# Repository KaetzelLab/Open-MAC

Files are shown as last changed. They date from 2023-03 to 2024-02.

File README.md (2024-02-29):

# Open-MAC
Design files for an open-source motorized all-in-one commutator (Open-MAC).

BOM is updated, and we kindly request the users to refer BOM from GitHub to build the new version of the commutator

#### For Opto-Ephys commutator please visit below link

https://github.com/KaetzelLab/Open-MAC-opto-ephys-commutator.git

## Multi-function overview

1-s2 0-S2468067223000366-gr3

## Overview of Commutator Design

Commutator overviewpng

## Commutator assembly 

https://github.com/KaetzelLab/Open-MAC/assets/71041273/7a731dc8-49ea-48de-bc95-c26bbd119e4d

## Ephys recording during LMA

https://github.com/KaetzelLab/Open-MAC/assets/71041273/e578357a-732e-4ff6-8649-cc418df18f86

# Citation
If you find this repository and documents useful cite us as 

Sampath K.T. Kapanaiah, Dennis Kätzel, (2023). Open-MAC: A low-cost open-source motorized commutator for electro- and opto-physiological recordings in freely moving rodents, HardwareX, Volume 14,2023,e00429, ISSN 2468-0672,https://doi.org/10.1016/j.ohx.2023.e00429.

Kapanaiah, Sampath K.T., & Kätzel, Dennis. (2023). Open-MAC: A low-cost open-source motorized commutator for electro- and opto-physiological recordings in freely moving rodents. https://doi.org/10.5281/zenodo.7640543

# If you are downloading files from zenodo

Please note that relative to v1.1 (currently only available on Zenodo, https://zenodo.org/record/7640543 ) this current version v1.2 contains two improvements:

 (i) The Top case B has been extended in length so that it can now be used for 4 of the 5 Open-MAC versions (12-channel SPI E-Phys, 24-channel SPI E-Phys, 1-channel RF miniscope, combined 12-channel SPI E-Phys/1-channel RF miniscope). As in previous versions, the combined E-Phys/Optogenetics version will require some minor modifications that we hope to release soon.

(ii) The bottom PCB design file, that suffered from one weak GND trace in v1.1 (but not in v1.0) has been updated, so that it is fully functional again.

Hence v1.1 is obsolete and v1.2, released here, should be used.

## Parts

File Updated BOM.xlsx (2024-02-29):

Designator | Component | Number | Cost per unit (EUR) | Total cost (EUR) | Manufacturer Number | Source of material | Material type
Top PCB | Top PCB | 1 | 1.00 | 1.00 | na | JLC PCB or PCB way | printed circuit board
Bottom PCB | Bottom PCB | 1 | 1.00 | 1.00 | na | JLC PCB or PCB way | printed circuit board
Bottom PCB | Hall Sensor | 2 | 0.30 | 0.60 | na | https://www.amazon.de/gp/product/B07ZDJSZSG/ref=ppx_yo_dt_b_asin_title_o04_s00?ie=UTF8&psc=1 | IC
Top PCB, Bottom PCB | slide switch | 2 | 0.42 | 0.84 | 1825232-1 | https://www.mouser.de/ProductDetail/TE-Connectivity-PB/1825232-1?qs=kTKVN3NWb5FosGxaNC1%252BtA%3D%3D | Plastic, Metal
Top PCB | Linear voltage drop out regulator (LDO) | 1 | 0.61 | 0.61 | MC7805BDTRKG | https://www.mouser.de/ProductDetail/onsemi/MC7805BDTRKG?qs=%252B9%2Fcbd0IE0RVSCV5SBH6%2FA%3D%3D | IC
Top PCB | Capacitors | 2 | 0.15 | 0.30 | 581-08055A101MAT2A | https://eu.mouser.com/ProductDetail/KYOCERA-AVX/08055A101MAT2A?qs=zdK0ZDdZmgzjgZCLHBg27Q%3D%3D | ceramic capacitor
Top PCB | Microcontroller (XIAO or XIAO ESP32C3) | 1 | 4.99 | 4.99 | XIAO ESP32C3 | https://www.seeedstudio.com/Seeed-XIAO-ESP32C3-p-5431.html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 | IC
Top PCB | DC Power jack barrel | 1 | 1.02 | 1.02 | 694106301002 | https://www.mouser.de/ProductDetail/Wurth-Elektronik/694106301002?qs=a9WhcLg8qCwOEkcI62k5mA%3D%3D | Plastic, Metal
Top PCB | Jumper | 1 | 0.70 | 0.70 | - | https://www.amazon.de/-/en/Black-Standard-Short-Circuit-Jumper/dp/B00R1LEP6G | Plastic, Metal
Top PCB | Stepper driver | 1 | 10.00 | 10.00 | TMC2208 or TMC2209 | https://www.amazon.de/-/en/dp/B0893DPSJL/ref=twister_B09V7H96P6?th=1 | IC, PCB
Top PCB | Connector 7P and 8P | 4 | 2.99 | 11.99 | - | https://www.amazon.de/-/en/Female-Straight-Connector-Arduino-Prototype/dp/B093LBN495?s=ce-de | plastic, metal
Top PCB, Bottom PCB | Resistors | 2 | 0.44 | 0.88 | MBA02040C1002FC100 | https://www.mouser.de/ProductDetail/Vishay-Beyschlag/MBA02040C1002FC100?qs=nlQjf3QnJCoHnMMMaOw%2FFA%3D%3D | metal film resistor
Top PCB, Bottom PCB | 2P Terminal Block Connector | 25 | 0.30 | 7.50 | - | https://www.amazon.de/gp/product/B08HWP26RB/ref=ppx_yo_dt_b_asin_image_o00_s00?ie=UTF8&psc=1 | plastic, metal
Center case A | Stepper motor | 1 | 22.00 | 22.00 | NEMA-7 | https://www.amazon.de/gp/product/B07SPK6BT4/ref=ppx_yo_dt_b_asin_title_o07_s00?ie=UTF8&psc=1 | metal, semiconductor
Magnet holder | Magnet (cylinder 3x4mm)** | 2 | 0.16 | 0.32 | - | https://www.kjmagnetics.com/proddetail.asp?prod=D22 | Neodynium
Center case A | Ball Bearing (7x42x30) | 1 | 2.60 | 2.60 | 6806-2RS | https://www.amazon.de/-/en/sourcing-6806-2RS-Groove-Bearing-Double/dp/B082PYHLC2?s=industrial | steel
Bottm case B | Ball Bearing ( 3 x 10 x 4 mm) | 1 | 0.90 | 0.90 | 623-2RS | https://www.amazon.de/gp/product/B07CWLGNJ5/ref=ppx_yo_dt_b_asin_title_o06_s00?ie=UTF8&psc=1 | steel
- | M2.5x5.7mm threaded inserts | 30 | 0.12 | 3.60 | - | https://www.amazon.de/dp/B088QJDPKK?psc=1&ref=ppx_yo2ov_dt_b_product_details | steel
- | M2.5x35mm Screws | 10 | 0.24 | 2.40 | - | https://www.amazon.de/-/en/US-SA-AJD-99450/dp/B012TE3VJG | steel
- | M2.5x8mm Screws | 20 | 0.18 | 3.60 | - | https://www.amazon.de/-/en/sourcingmap-Button-Hexagon-Socket-Screw/dp/B01D4VH1YO | steel
- | M3x4mm threaded inserts | 4 | 0.09 | 0.36 | - | https://www.amazon.de/-/en/ruthex-Threaded-Insert-RX-M3x5-7-Ultrasonic/dp/B08BCRZZS3 | brass
- | M3x6mm screws | 3 | 0.07 | 0.21 | - | https://www.amazon.de/-/en/countersunk-screws-hexagon-socket-pieces/dp/B07YZGR7ZC | steel
- | M3x50mm screws | 1 | 0.17 | 0.17 | - | https://www.amazon.de/-/en/countersunk-screws-hexagon-socket-pieces/dp/B07YZM98J3 | steel
3D printed parts | 3D printed parts | 1 | - | 60.00 | - | -
Sum total of costs for any commutator type |  |  |  | 137.59
Parts that are ordered in dependence on the specific commutator type to be built
Top PCB, Bottom PCB | SMA Connector (Miniscope)* | 0 / 2 | 7.13 | 14.26 | 73251-2209 | https://www.mouser.de/ProductDetail/Molex/73251-2209?qs=vxeUf0TWHS1jQq9gJekxHg%3D%3D | gold-plated metal
Top PCB, Bottom PCB | Omnetics Horizontal SMT PZN-12-AA* | 0 / 2 / 4 | 42.39 | 84.78 | A79623-001 | https://www.omnetics.com/products/neuro-connectors/nano-strip-polarized | composite
slip-ring | slip-ring for 12-channel SPI* | 0 / 1 | 20.00 | 20.00 | M220A-18 / M125-18 | https://www.senring.com/capsule-slip-ring/m220.html | plastic, conductive material
slip-ring | slip-ring for 24-channel SPI* | 0 / 1 | 75.00 | 75.00 | M220A-36 | https://www.senring.com/capsule-slip-ring/m220.html | plastic, conductive material
slip-ring | slip-ring for high-speed RF-line* | 0 / 1 | 85.00 | 85.00 | O022-12 / O022-08 | https://www.senring.com/hd-sdi-1080p-slip-ring/o022-12.html | plastic, conductive material
slip-ring | slip-ringfor 12-channel SPI & RF-line* | 0 / 1 | 145.00 | 145.00 | O032-24 | https://www.senring.com/hd-sdi-1080p-slip-ring/o032-24.html | plastic, conductive material
slip-ring | slip-ring for 12-channel SPI & through-hole* | 0 / 1 | 130.00 | 130.00 | H1532-24S | https://www.senring.com/through-hole-slip-ring/small-hole/h1532.html | plastic, conductive material
Sum total of costs for specific commutator type
Electrophysiology 12-channel SPI (32 recording channels) |  |  |  | 242.37
Electrophysiology 24-channel SPI (64 recording channels) |  |  |  | 382.15
Miniscope only |  |  |  | 236.85
Electrophysiology 12-channel SPI (32 recording channels) and Miniscope |  |  |  | 381.63
Electrophysiology 12-channel SPI (32 recording channels) and Optogenetics |  |  |  | 352.38
* Distinct numbers are stated for these items because their usage depends on the type of commutator that is built. At the bottom of the table, all 5 types that can be built with the unmodified design files provided here and on https://zenodo.org/record/7253652 are listed and their costs are stated.
** Alternative source at a price of 0.30 €/unit: https://www.amazon.de/-/en/10-Mini-Neodymium-Magnets-Ultra-Strong-Original/dp/B01JEK4A4I

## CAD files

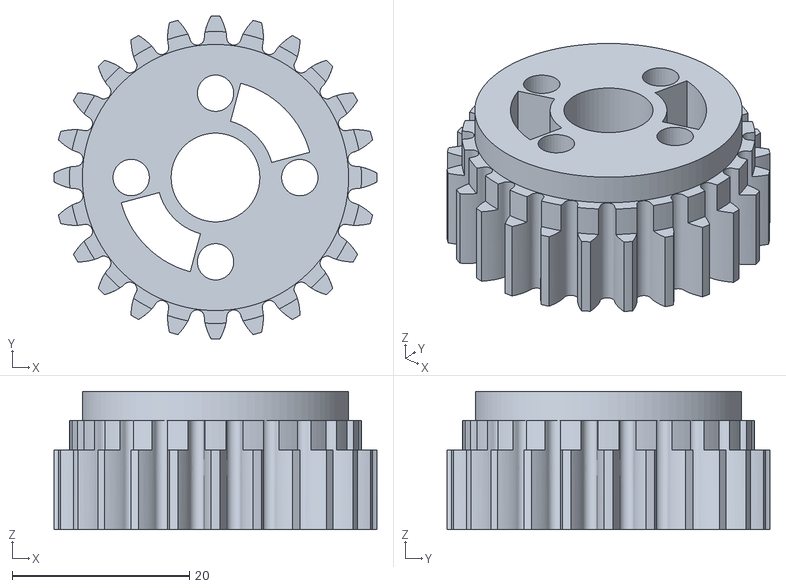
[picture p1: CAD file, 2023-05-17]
Open-MAC stl design files/6-Com Bearing Spur Gear.stl
36.4 x 36.4 x 15.6

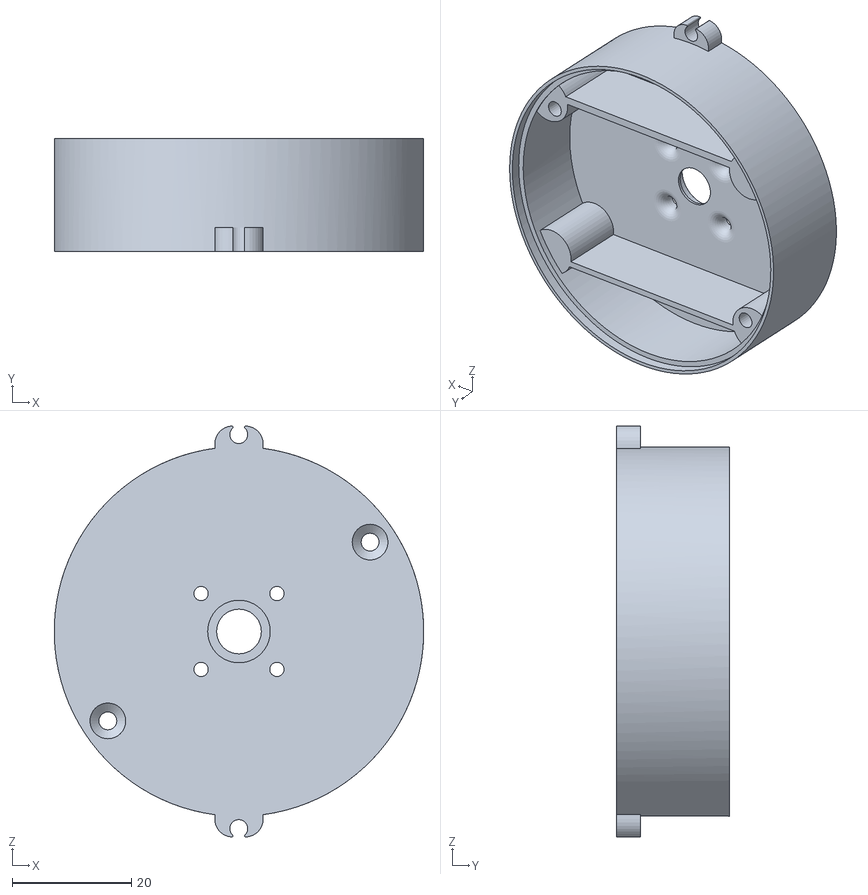
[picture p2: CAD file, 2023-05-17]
Open-MAC stl design files/10-Com_Bottom_B.stl
62.0 x 18.9 x 69.0

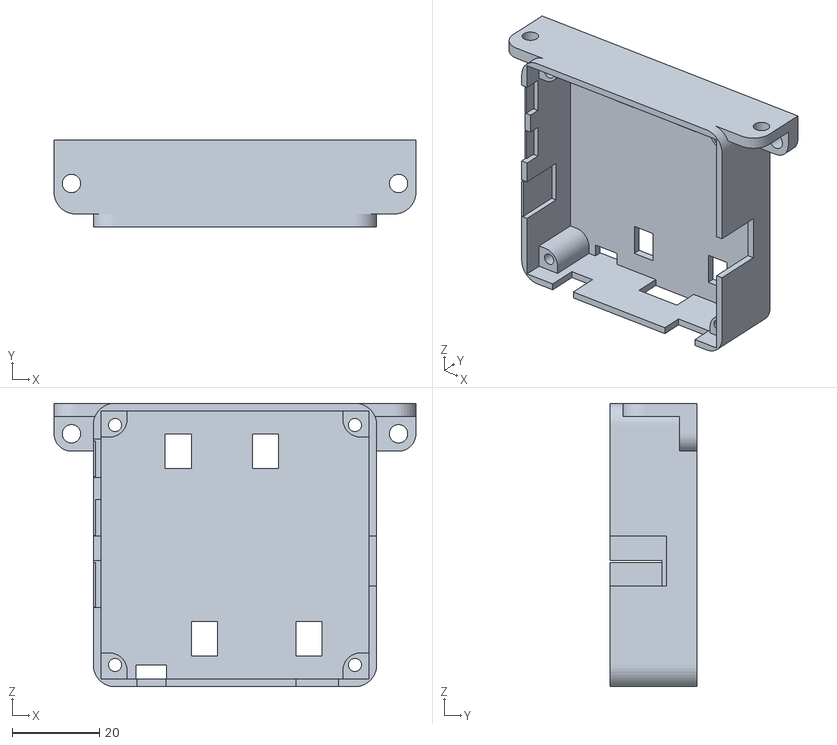
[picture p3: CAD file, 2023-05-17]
Open-MAC stl design files/1-Com_Top_A.stl
83.0 x 20.0 x 65.0

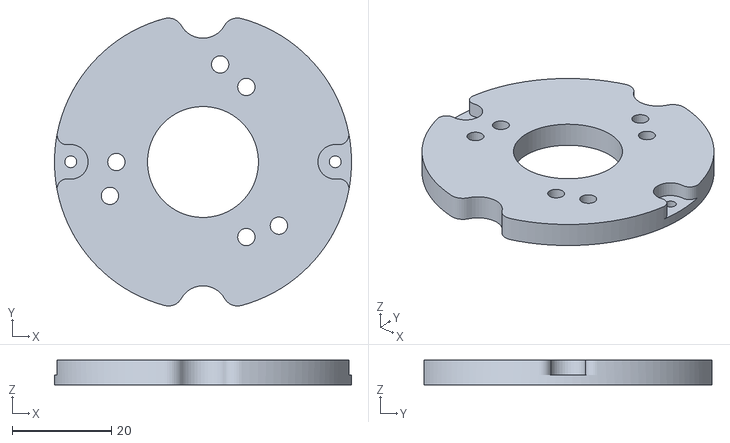
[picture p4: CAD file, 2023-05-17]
Open-MAC stl design files/3-Com Slip ring stage (only for regular slipring).stl
60.0 x 58.2 x 5.00

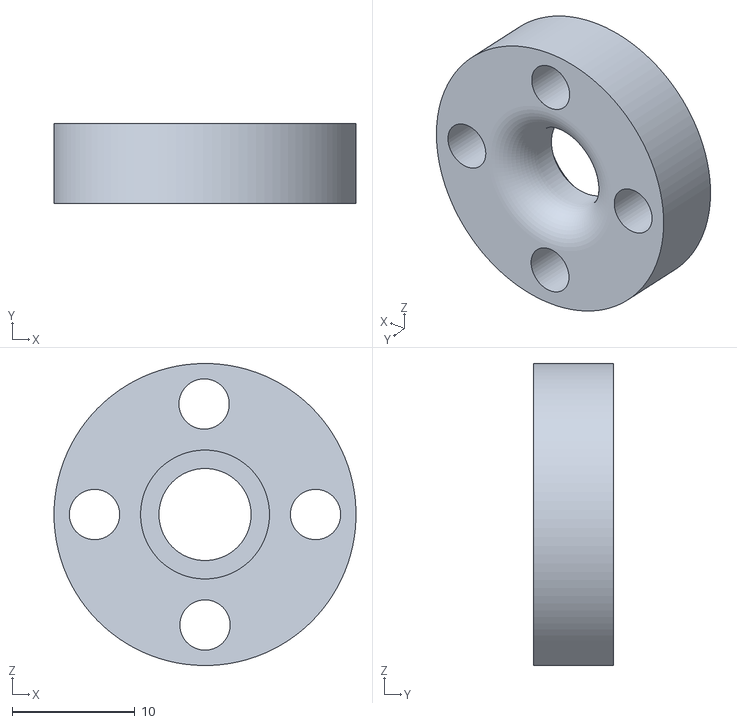
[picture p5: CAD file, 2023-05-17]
Open-MAC stl design files/11-Com_Bottom_C.stl
24.6 x 6.50 x 24.6

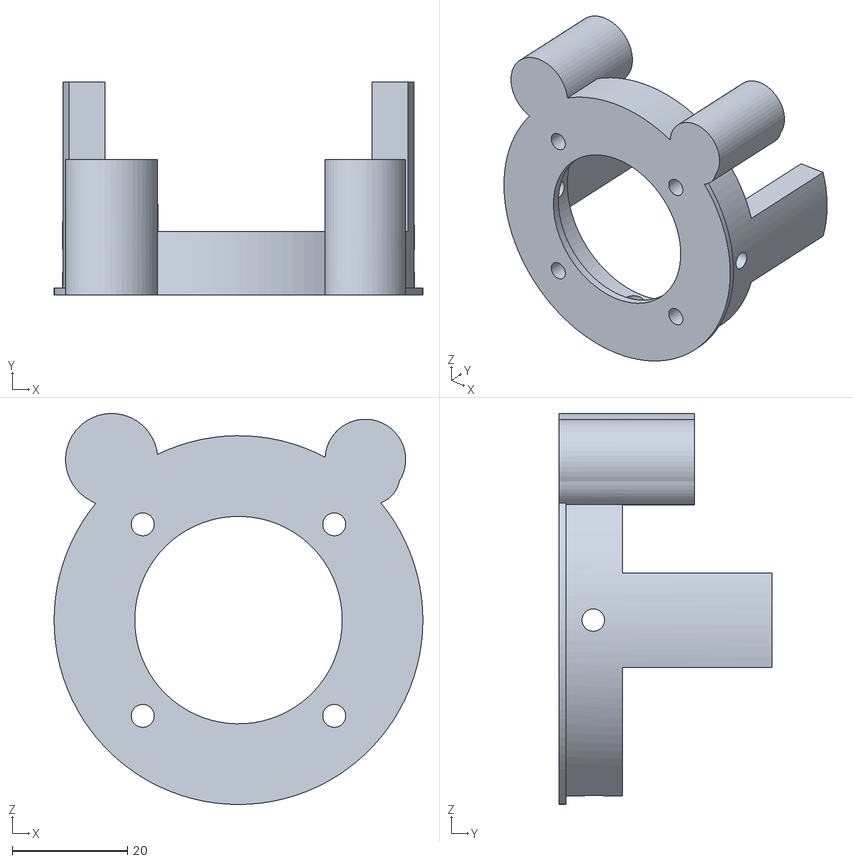
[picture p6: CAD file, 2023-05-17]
Open-MAC stl design files/4-Com Center case A.stl
64.0 x 37.0 x 67.9

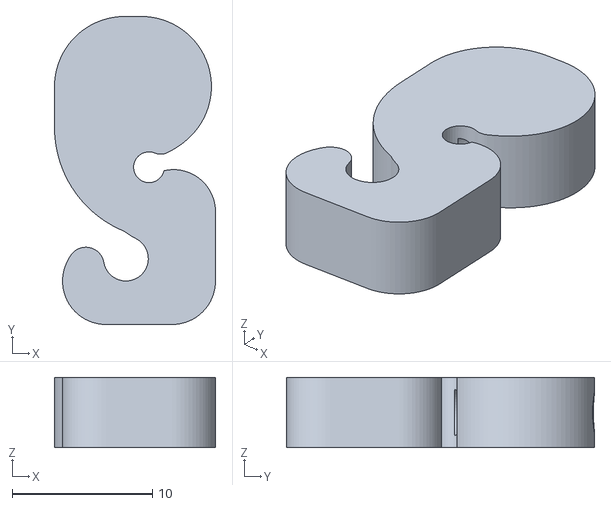
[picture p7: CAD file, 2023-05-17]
Open-MAC stl design files/13-Com horizontal cable holder.stl
11.5 x 22.0 x 5.00

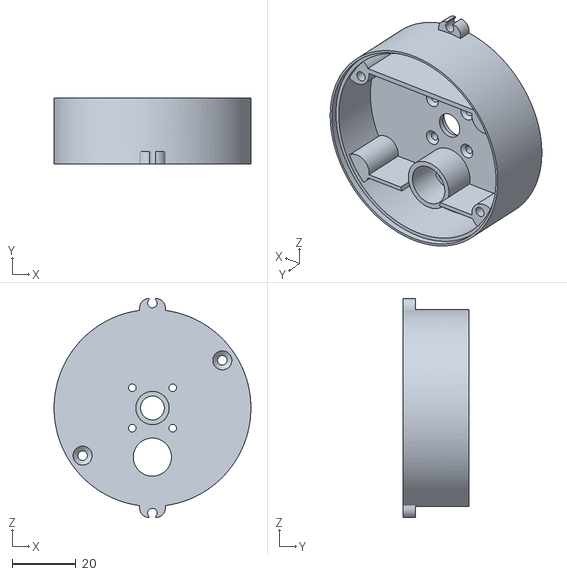
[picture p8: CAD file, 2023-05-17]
Open-MAC stl design files/Com_Bottom_B (Only for optical fiber pass thorugh experiments).stl
62.0 x 20.9 x 69.0

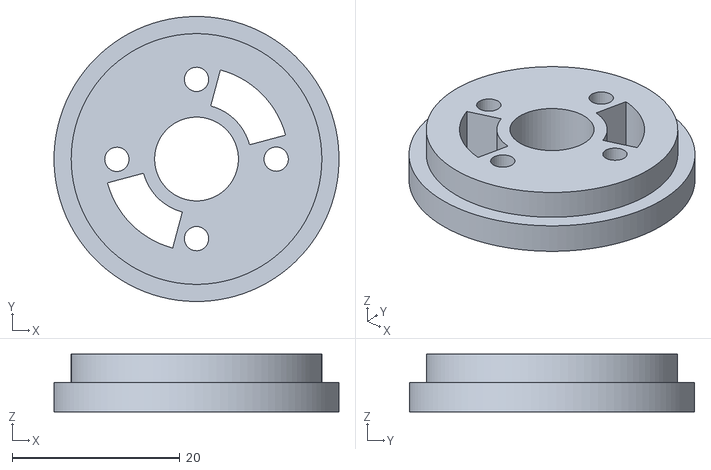
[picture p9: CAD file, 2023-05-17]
Open-MAC stl design files/8-Com Bearing Inner Adapter.stl
34.0 x 34.0 x 6.90

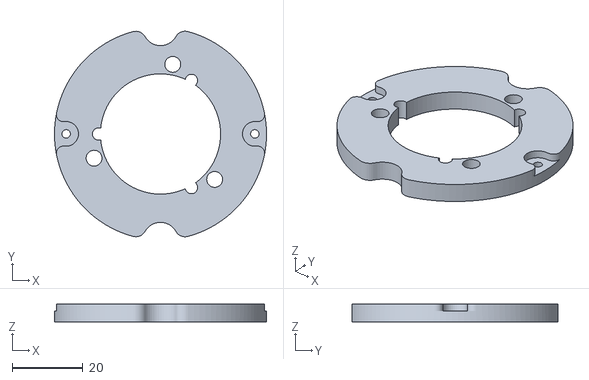
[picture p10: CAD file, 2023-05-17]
Open-MAC stl design files/Com Slip ring stage ( only use for Ephys+Miniscope slip ring).stl
60.0 x 58.2 x 5.00

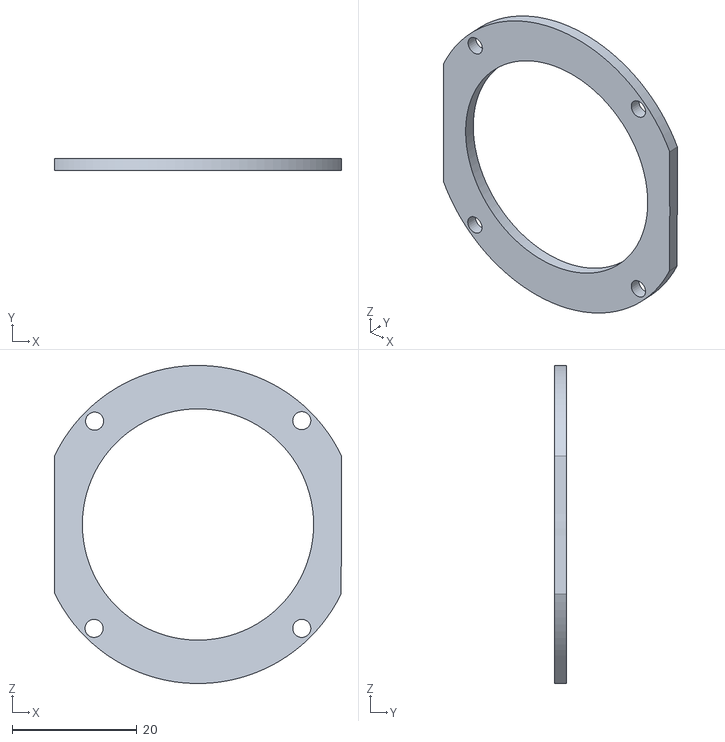
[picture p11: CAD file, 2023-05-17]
Open-MAC stl design files/5-Com Center case B.stl
46.0 x 2.00 x 50.9

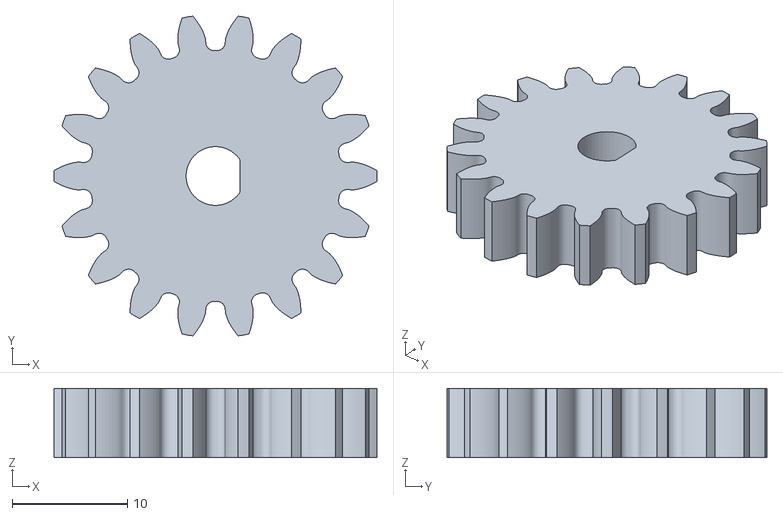
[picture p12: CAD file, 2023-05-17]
Open-MAC stl design files/7-Com Stepper Spur Gear.stl
28.0 x 27.7 x 6.00

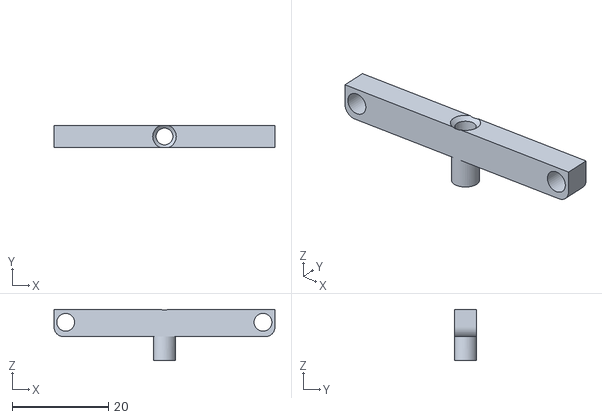
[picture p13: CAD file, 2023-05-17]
Open-MAC stl design files/12-Com Magnet holder.stl
46.0 x 4.60 x 10.7

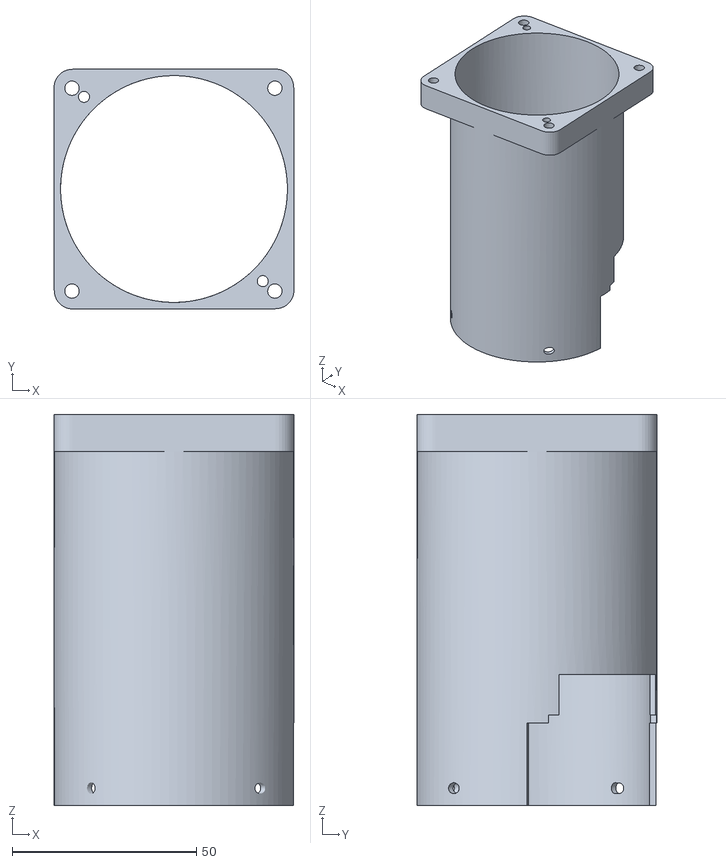
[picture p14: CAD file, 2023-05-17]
Open-MAC stl design files/2-Com_Top_B.stl
65.1 x 65.1 x 106.0

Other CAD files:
Open-MAC stl design files/9-Com_Bottom_A.stl
Open-MAC f3d design files/Com Center Bearing Assembly.f3d
Open-MAC f3d design files/Com Magnet holder.f3d
Open-MAC f3d design files/Com Top A.f3d
Open-MAC f3d design files/Com Top B.f3d
Open-MAC f3d design files/Com horizontal cable holder.f3d
Open-MAC f3d design files/Commutator bottom.f3d
Open-MAC f3d design files/SlipRing_Mount v1.2.f3d

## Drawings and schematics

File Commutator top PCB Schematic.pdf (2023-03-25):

SCLK- | T2 OE1
SCLK- | T2 OE2

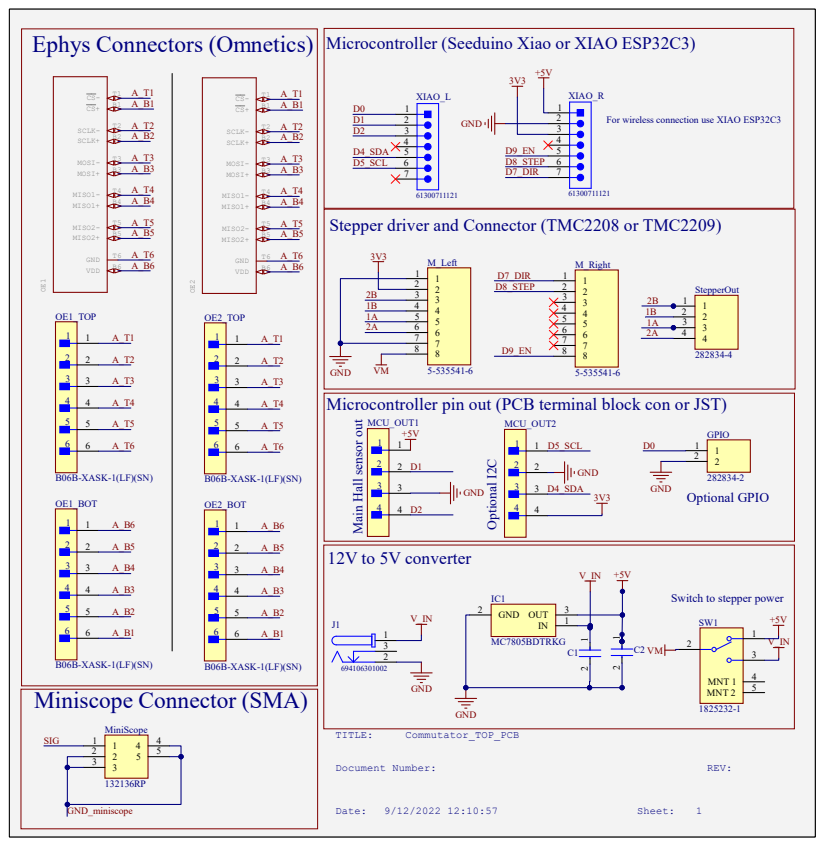
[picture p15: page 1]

Microcontroller (Seeduino Xiao or XIAO ESP32C3)

For wireless connection use XIAO ESP32C3

Switch to stepper power

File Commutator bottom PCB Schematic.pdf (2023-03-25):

SCLK- | T2 OE1
SCLK- | T2 OE2

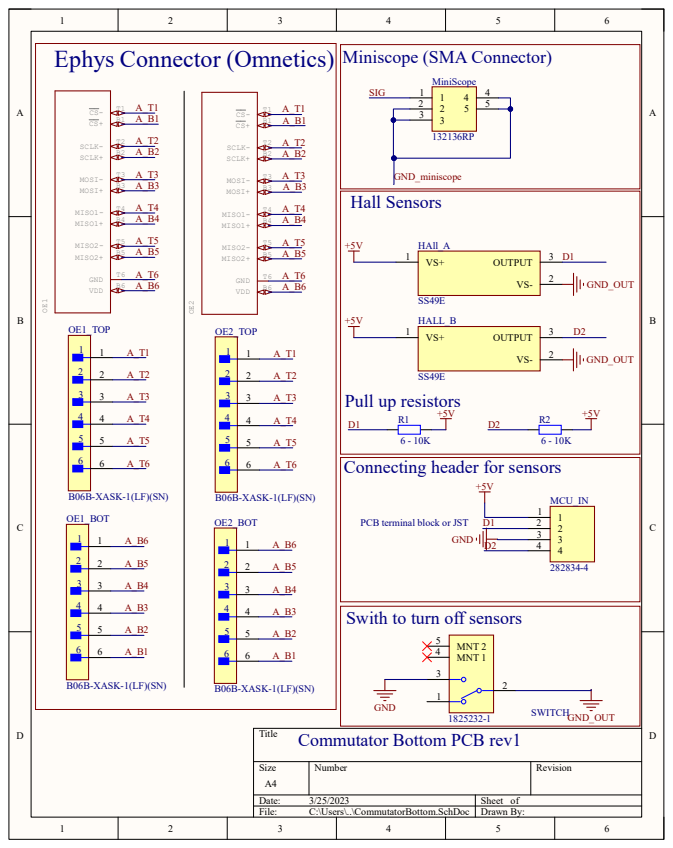
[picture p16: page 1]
Size; Number; Revision; Date:; Sheet of; File:; C:\Users\..\CommutatorBottom.SchDoc; Drawn By:; OE1_TOP; OE1_BOT; MISO2-; MISO1+; MISO2+; VDD; GND; MOSI-; SCLK+; MISO1-; MOSI+; OE2_TOP; OE2_BOT; MiniScope; GND_miniscope; SIG; OUTPUT; HAll_A; HALL_B; GND_OUT; Hall Sensors; MNT 1 4; MNT 2 5; SWITCH 1825232-1; MCU_IN

Ephys Connector (Omnetics) Miniscope (SMA Connector)

Pull up resistors

Connecting header for sensors

B06B-XASK-1(LF)(SN)

PCB terminal block or JST

Swith to turn off sensors

Title
Commutator Bottom PCB rev1

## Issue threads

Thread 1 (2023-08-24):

A version use 16-channel SPI

Fusenheizi, 2023-08-24:
Thank you very much for this project! It is well suited for my Intan RHD system.

Additionally, I also use the **Intan RHS system** for animal stimulation, and the corresponding cable connector is the **Omnetics PZN-16 polarized nano**. Is there a version based on this available?

KaetzelLab, 2023-08-24:
Thank you very much for your appreciation, Unfortunately, we do not have  PZN-16 polarized, I will upload the Altium design file sooner and maybe you can modify it with a PZN-16 polarized nano footprint.

Fusenheizi, 2023-08-24:
> Thank you very much for your appreciation, Unfortunately, we do not have  PZN-16 polarized, I will upload the Altium design file sooner and maybe you can modify it with a PZN-16 polarized nano footprint.

Thank you for your response! I will make modifications based on the file you uploaded later.

KaetzelLab, 2023-09-06:
https://github.com/KaetzelLab/Open-MAC/PCB Altium files files.zip

KaetzelLab, 2023-09-06:
https://github.com/KaetzelLab/Open-MAC/PCB Altium files files.zip

KaetzelLab, 2023-09-06:
https://github.com/KaetzelLab/Open-MAC/PCB Altium files files.zip

KaetzelLab, 2023-09-06:
https://github.com/KaetzelLab/Open-MAC/PCB Altium files files.zip

Closed 2023-09-06.

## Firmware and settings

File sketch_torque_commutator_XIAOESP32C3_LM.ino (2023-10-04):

//this is sketch file for torque mode operation of Open-MAC commutator
int dirPin = D7;   // Direction was 7
int stepPin = D8;  // Step
int EnPin = D9;    // Enable was 9

int sensorReading_delay = 0;
int step_delay_dur = 500;
int stepsPerRevolution = 50;

void setup() {
  Serial.begin(9600);
  // initial speed and the target position
  pinMode(EnPin, OUTPUT);
  pinMode(dirPin, OUTPUT);
  pinMode(stepPin, OUTPUT);
  // Hall sensors
  pinMode(A1, INPUT);
  pinMode(A2, INPUT);
  digitalWrite(EnPin, HIGH);
}

void loop() {
  if (digitalRead(A2) == 0) {
    digitalWrite(dirPin, HIGH);
    digitalWrite(EnPin, LOW);
    for (int i = 0; i < stepsPerRevolution; i++) {
      digitalWrite(stepPin, HIGH);
      delayMicroseconds(step_delay_dur);
      digitalWrite(stepPin, LOW);
      delayMicroseconds(step_delay_dur);
    }
    digitalWrite(EnPin, HIGH);
  } else if (digitalRead(A1) == 0) {
    digitalWrite(dirPin, LOW);
    digitalWrite(EnPin, LOW);
    for (int i = 0; i < stepsPerRevolution; i++) {
      digitalWrite(stepPin, HIGH);
      delayMicroseconds(step_delay_dur);
      digitalWrite(stepPin, LOW);
      delayMicroseconds(step_delay_dur);
    }
    digitalWrite(EnPin, HIGH);
  }
}

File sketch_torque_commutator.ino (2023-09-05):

//this is sketch file for torque mode operation of Open-MAC commutator 
int dirPin  = A7;  // Direction
int stepPin = A8; // Step
int EnPin   = A9; // Enable

// Define Hall sensor connections
#define HALL_SENSOR_A      A1
#define HALL_SENSOR_B      A2
int sensorReading_delay   = 0;
int step_delay_dur = 300;
int stepsPerRevolution = 50;

void setup() {
  // initial speed and the target position
  pinMode(EnPin,OUTPUT);
  pinMode(dirPin, OUTPUT);
  pinMode(stepPin, OUTPUT);
  // Hall sensors 
  pinMode(HALL_SENSOR_A, INPUT);
  pinMode(HALL_SENSOR_B, INPUT);
  attachInterrupt(digitalPinToInterrupt(HALL_SENSOR_A), move_backward, LOW);  
  attachInterrupt(digitalPinToInterrupt(HALL_SENSOR_B), move_forward, LOW);    
}
void move_forward(){ 
  digitalWrite(dirPin, LOW); 
  digitalWrite(EnPin, LOW);
  // Spin the stepper motor 1 revolution quickly:
  for (int i = 0; i < stepsPerRevolution; i++) {
    // These four lines result in 1 step:
    digitalWrite(stepPin, HIGH);
    delayMicroseconds(step_delay_dur);
    digitalWrite(stepPin, LOW);
    delayMicroseconds(step_delay_dur);    
  }   
}
void move_backward(){   
  digitalWrite(dirPin, HIGH);
  digitalWrite(EnPin, LOW);
  // Spin the stepper motor 1 revolution quickly:
  for (int i = 0; i < stepsPerRevolution; i++) {
    // These four lines result in 1 step:
    digitalWrite(stepPin, HIGH);    
    delayMicroseconds(step_delay_dur);
    digitalWrite(stepPin, LOW);
    delayMicroseconds(step_delay_dur);
  }    
}  
void loop() { 
  digitalWrite(EnPin, HIGH);
  delayMicroseconds(sensorReading_delay); 
 
 }

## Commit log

2023-02-11 Create Bottom PCB
2023-06-15 Add files via upload
    added drill files
2023-09-05 Update sketch_torque_commutator.ino
    Add code to turn off En pin when commutator is not rotating to prevent overheating of the stepper motor.
    [sketch_torque_commutator.ino]
2023-09-06 PCB Altium source files
2024-02-29 Add files via upload
    attached updated BOM
    [Updated BOM.xlsx]
